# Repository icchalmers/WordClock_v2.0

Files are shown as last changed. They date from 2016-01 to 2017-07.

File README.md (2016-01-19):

# WordClock_v2.0

This is a **work-in-progress** build of a word clock. It was originally my final project as part [Fab Academy 2015](http://www.fabacademy.org/) at [Fab Lab Strathclyde](http://www.strath.ac.uk/fablab/).
You can follow the inital evolution of the clock [on my class website](http://fabacademy.org/archives/2015/eu/students/chalmers.iain/final-project-summary-wordclock20.html). The content is also mirrored to [my GitHub Pages site](http://icchalmers.github.io/final-project-summary-wordclock20.html).

This clock is an evolution of [WordClock_v1.0](https://github.com/icchalmers/WordClock_v1.0).

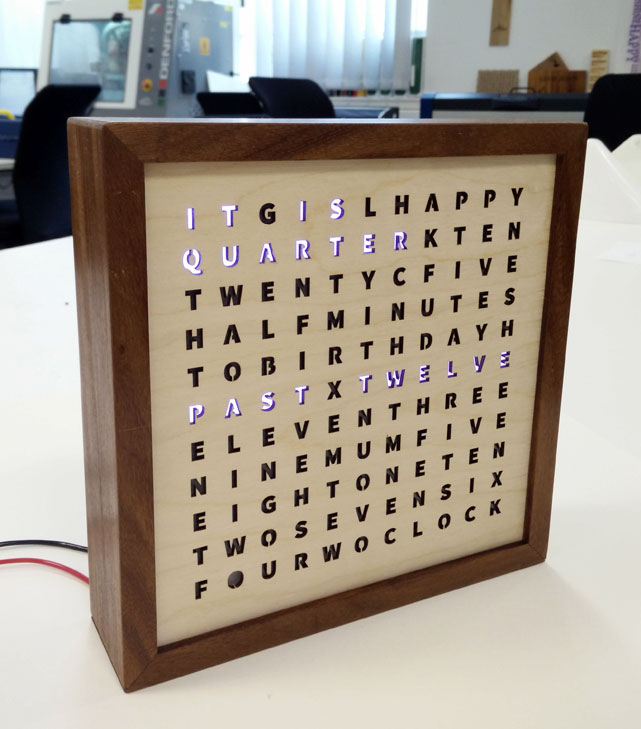
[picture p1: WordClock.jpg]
WordClock


# Project Parts

## Model
The 'Model' folder contains all the Autodesk Inventor 2015 CAD files for the clock. 

The file `Model/wordClock.ipt` is VERY customisable, but has no mounting holes for electronics or any mechanism to support the LED strips.

The 'Model/SolidifiedClockToMake' folder contains a locked down version of the clock i.e. it uses a grid of 11x11. Some parameters may or may not still be adjustable. It has additional holes added to the middle plate for mounting control electronics and holding the LED strips in place.

The main file for the clock is `wordClock_NonParametric.ipt`. The other .ipt files are the individual pieces and are derived from `wordClock_NonParametric.ipt`. They have been compensated for laser kerf using the "kerf" parameter in the master model.

The file `PartsForExport.dwg` has a layout of each of the individual parts. If you change a parameter in the master model, update the individual parts and then update the .dwg.

The lettering is added in CorelDraw - Inventor is a bit rubbish at handling text. I used a modified version of [Source Sans Pro](https://www.google.com/fonts/specimen/Source+Sans+Pro) i.e. I added little structures to support the internal parts of letters.

## hw
The 'hw' folder has the KiCAD files for the two PCB designs: the main control board and the power distribution boards. The power distribution boards also help hold the LED strips in place.

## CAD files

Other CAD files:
Model/SolidifiedClockToMake/PartsForImport_Ply3mm_Kerf0.05mm.dwg
Model/SolidifiedClockToMake/PartsLayout.dwg
Model/SolidifiedClockToMake/Back.ipt
Model/SolidifiedClockToMake/Bottom.ipt
Model/SolidifiedClockToMake/Front.ipt
Model/SolidifiedClockToMake/FrontGrid.ipt
Model/SolidifiedClockToMake/GridHo.ipt
Model/SolidifiedClockToMake/GridVert.ipt
Model/SolidifiedClockToMake/LEDSupport.ipt
Model/SolidifiedClockToMake/Left.ipt
Model/SolidifiedClockToMake/Middle.ipt
Model/SolidifiedClockToMake/Right.ipt
Model/SolidifiedClockToMake/Top.ipt
Model/SolidifiedClockToMake/wordClock_NonParametric.ipt
Model/wordClock.ipt

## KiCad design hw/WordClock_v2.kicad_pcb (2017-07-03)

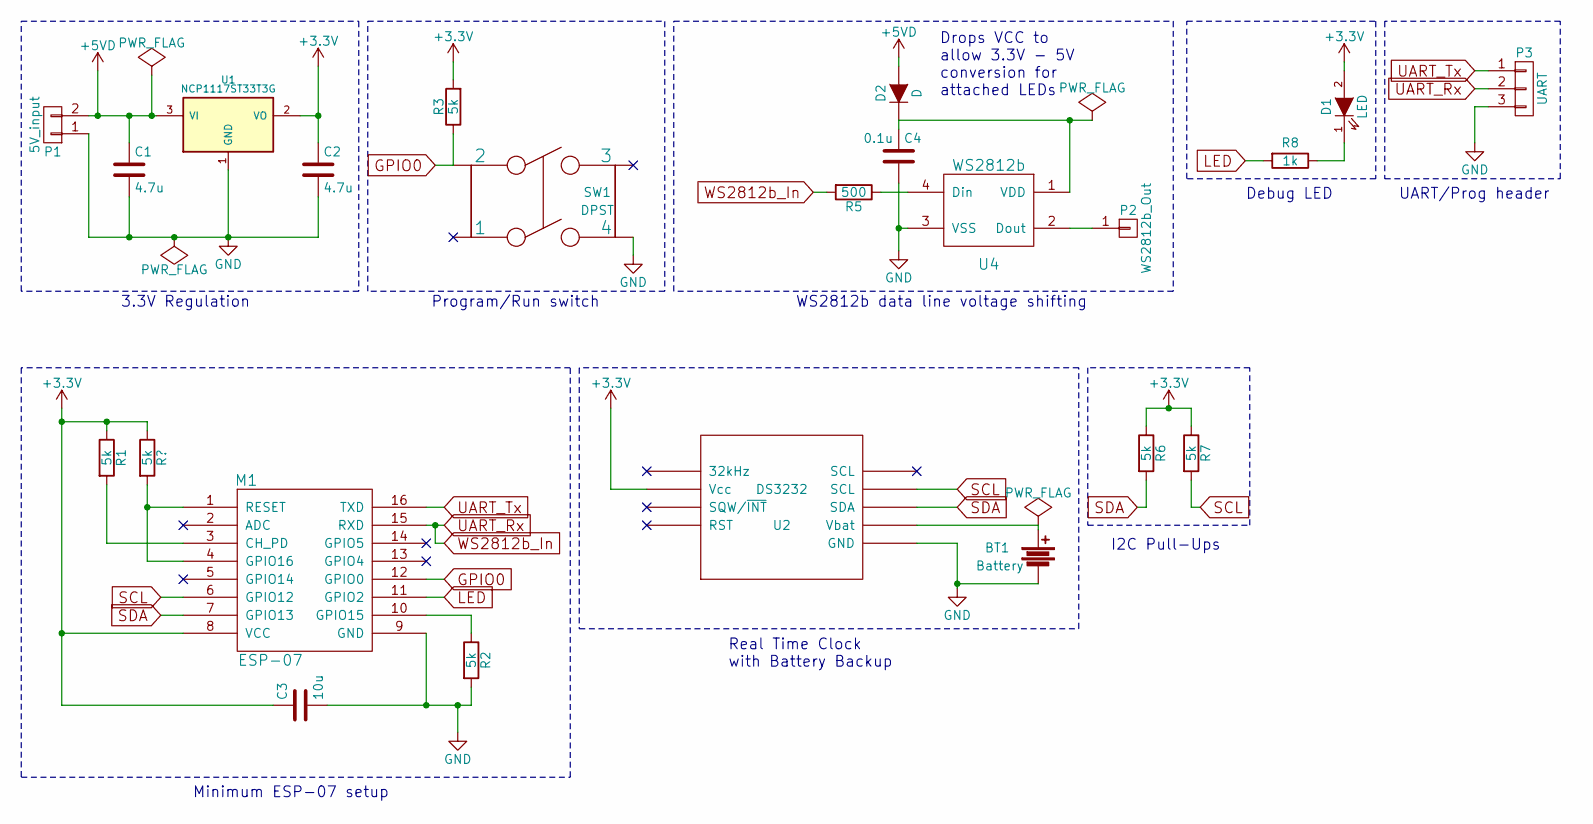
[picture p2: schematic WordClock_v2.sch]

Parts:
BT1: Battery; Battery_Holder_Cell_20mm_smd
C1, C2: 4.7u; C_1206_HandSoldering_IainEdit
C3: 10u; C_1206_HandSoldering_IainEdit
C4: 0.1u; C_1206_HandSoldering_IainEdit
D1: LED; C_1206_HandSoldering_IainEdit
D2: D; SOD-123F_HandSolder
M1: ESP-07
P1: 5V_input; Socket_Strip_Straight_1x02
P2: WS2812b_Out; Socket_Strip_Straight_1x01
P3: UART; Socket_Strip_Straight_1x03_IainEdit
R1, R2, R3, R6, R7: 5k; C_1206_HandSoldering_IainEdit
R5: 500; C_1206_HandSoldering_IainEdit
R8: 1k; C_1206_HandSoldering_IainEdit
SW1: DPST; FSM2JSMA_DPST_PushButton
U1: NCP1117ST33T3G; SOT223_HandSolder
U2: DS3232; Maxim_SOIC-20_W20-H2
U4: WS2812b; WS2812b_handsolder

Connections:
+3V3: C2.1, C3.1, D1.2 (A), M1.8 (VCC), R1.1, R3.2, R6.1, R7.1, U1.2 (VO), U2.4 (Vcc); also elsewhere on the board
+5VD: C1.1, D2.2 (A), P1.2, U1.3 (VI)
GND: BT1.2, C1.2, C2.2, C3.2, C4.2, M1.9 (GND), P1.1, P3.3, R2.2, SW1.4, U1.1 (GND), U2.15 (GND), U4.3 (VSS)
GPIO0: M1.12 (GPIO0), R3.1, SW1.2
LED: M1.11 (GPIO2), R8.2
unnamed: BT1.1, U2.16 (Vbat)
unnamed: C4.1, D2.1 (K), U4.1 (VDD)
unnamed: D1.1 (K), R8.1
unnamed 8: M1.1 (RESET), M1.4 (GPIO16); also elsewhere on the board
unnamed: M1.3 (CH_PD), R1.2
unnamed: M1.10 (GPIO15), R2.1
unnamed: P2.1, U4.2 (Dout)
unnamed: R5.1, U4.4 (Din)
SCL: M1.6 (GPIO12), R7.2, U2.18 (SCL)
SDA: M1.7 (GPIO13), R6.2, U2.17 (SDA)
UART_Rx: M1.15 (RXD), P3.2, R5.2
UART_Tx: M1.16 (TXD), P3.1

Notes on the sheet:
3.3V Regulation
WS2812b data line voltage shifting
Real Time Clock with Battery Backup
I2C Pull-Ups
Debug LED
UART/Prog header
Program/Run switch
Minimum ESP-07 setup
Drops VCC to allow 3.3V - 5V conversion for attached LEDs

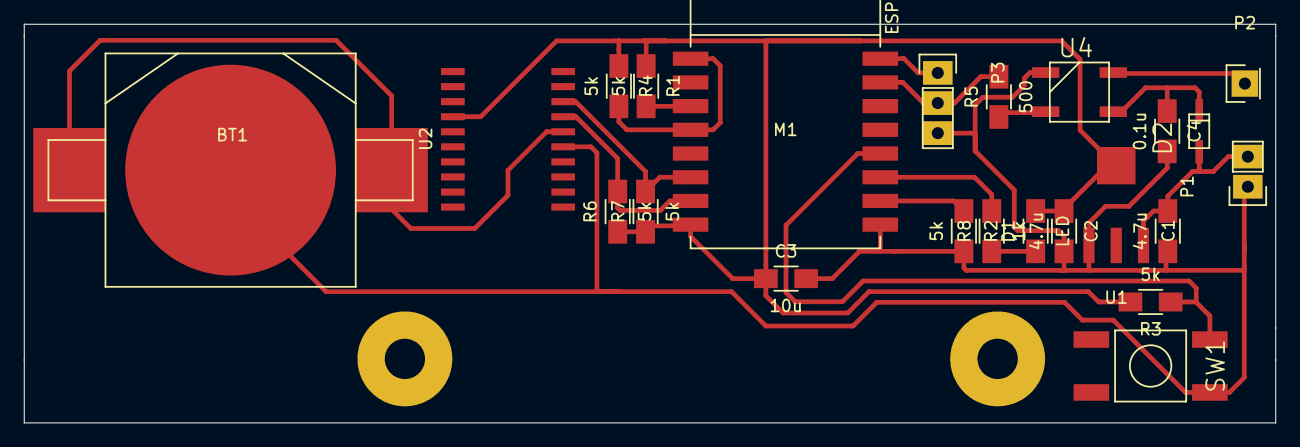
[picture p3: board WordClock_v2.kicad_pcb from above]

Board: 2 copper layers, 105.5 x 33.6 mm, 23 parts (0 on the bottom side), 17 nets.

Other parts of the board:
R4: 5k; C_1206_HandSoldering_IainEdit

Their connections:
+3V3: R4.1; also elsewhere on the board
unnamed 8: R4.2; also elsewhere on the board

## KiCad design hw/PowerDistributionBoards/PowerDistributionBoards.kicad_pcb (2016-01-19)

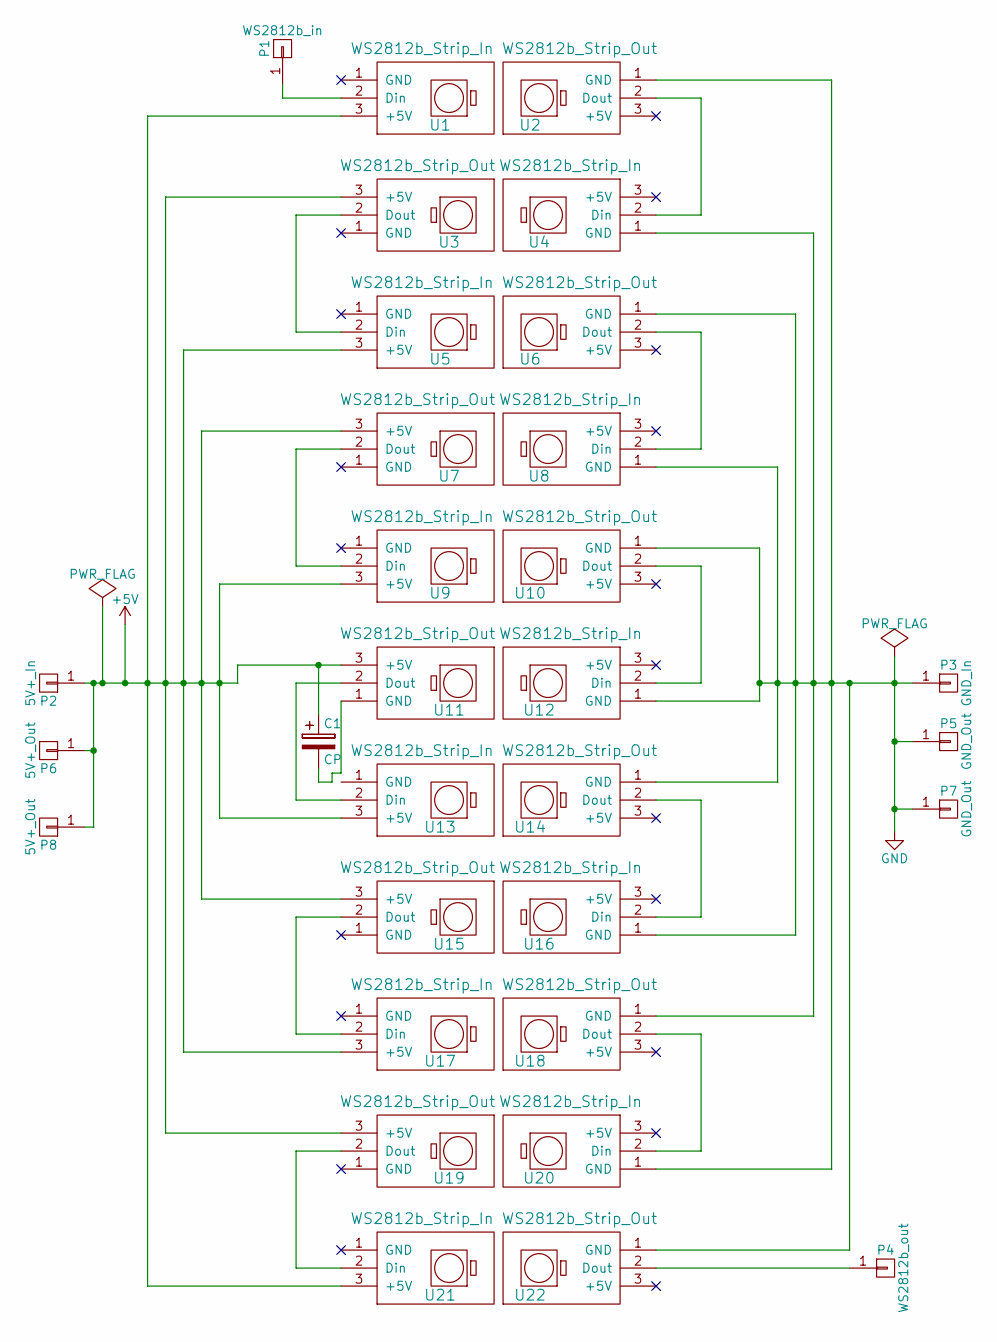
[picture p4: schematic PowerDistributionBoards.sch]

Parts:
C1: CP; Elko_vert_11.5x8mm_RM3.5
P1: WS2812b_in; Socket_Strip_Straight_1x01
P2: 5V+_In; Socket_Strip_Straight_1x01
P3: GND_In; Socket_Strip_Straight_1x01
P4: WS2812b_out; Socket_Strip_Straight_1x01
P5, P7: GND_Out; Socket_Strip_Straight_1x01
P6, P8: 5V+_Out; Socket_Strip_Straight_1x01
U1, U4, U5, U8, U9, U12, U13, U16, U17, U20, U21: WS2812b_Strip_In; WS2812b_strip_conn
U2, U3, U6, U7, U10, U11, U14, U15, U18, U19, U22: WS2812b_Strip_Out; WS2812b_strip_conn

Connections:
+5V: C1.1, P2.1, P6.1, P8.1, U1.3 (+5V), U3.3 (+5V), U5.3 (+5V), U7.3 (+5V), U9.3 (+5V), U11.3 (+5V), U13.3 (+5V), U15.3 (+5V), U17.3 (+5V), U19.3 (+5V), U21.3 (+5V)
GND: P3.1, P5.1, P7.1, U2.1 (GND), U4.1 (GND), U6.1 (GND), U8.1 (GND), U10.1 (GND), U12.1 (GND), U14.1 (GND), U16.1 (GND), U18.1 (GND), U20.1 (GND), U22.1 (GND)
unnamed: C1.2, U11.1 (GND)
unnamed: P1.1, U1.2 (Din)
unnamed: P4.1, U22.2 (Dout)
unnamed: U2.2 (Dout), U4.2 (Din)
unnamed: U3.2 (Dout), U5.2 (Din)
unnamed: U6.2 (Dout), U8.2 (Din)
unnamed: U7.2 (Dout), U9.2 (Din)
unnamed: U10.2 (Dout), U12.2 (Din)
unnamed: U11.2 (Dout), U13.2 (Din)
unnamed: U14.2 (Dout), U16.2 (Din)
unnamed: U15.2 (Dout), U17.2 (Din)
unnamed: U18.2 (Dout), U20.2 (Din)
unnamed: U19.2 (Dout), U21.2 (Din)

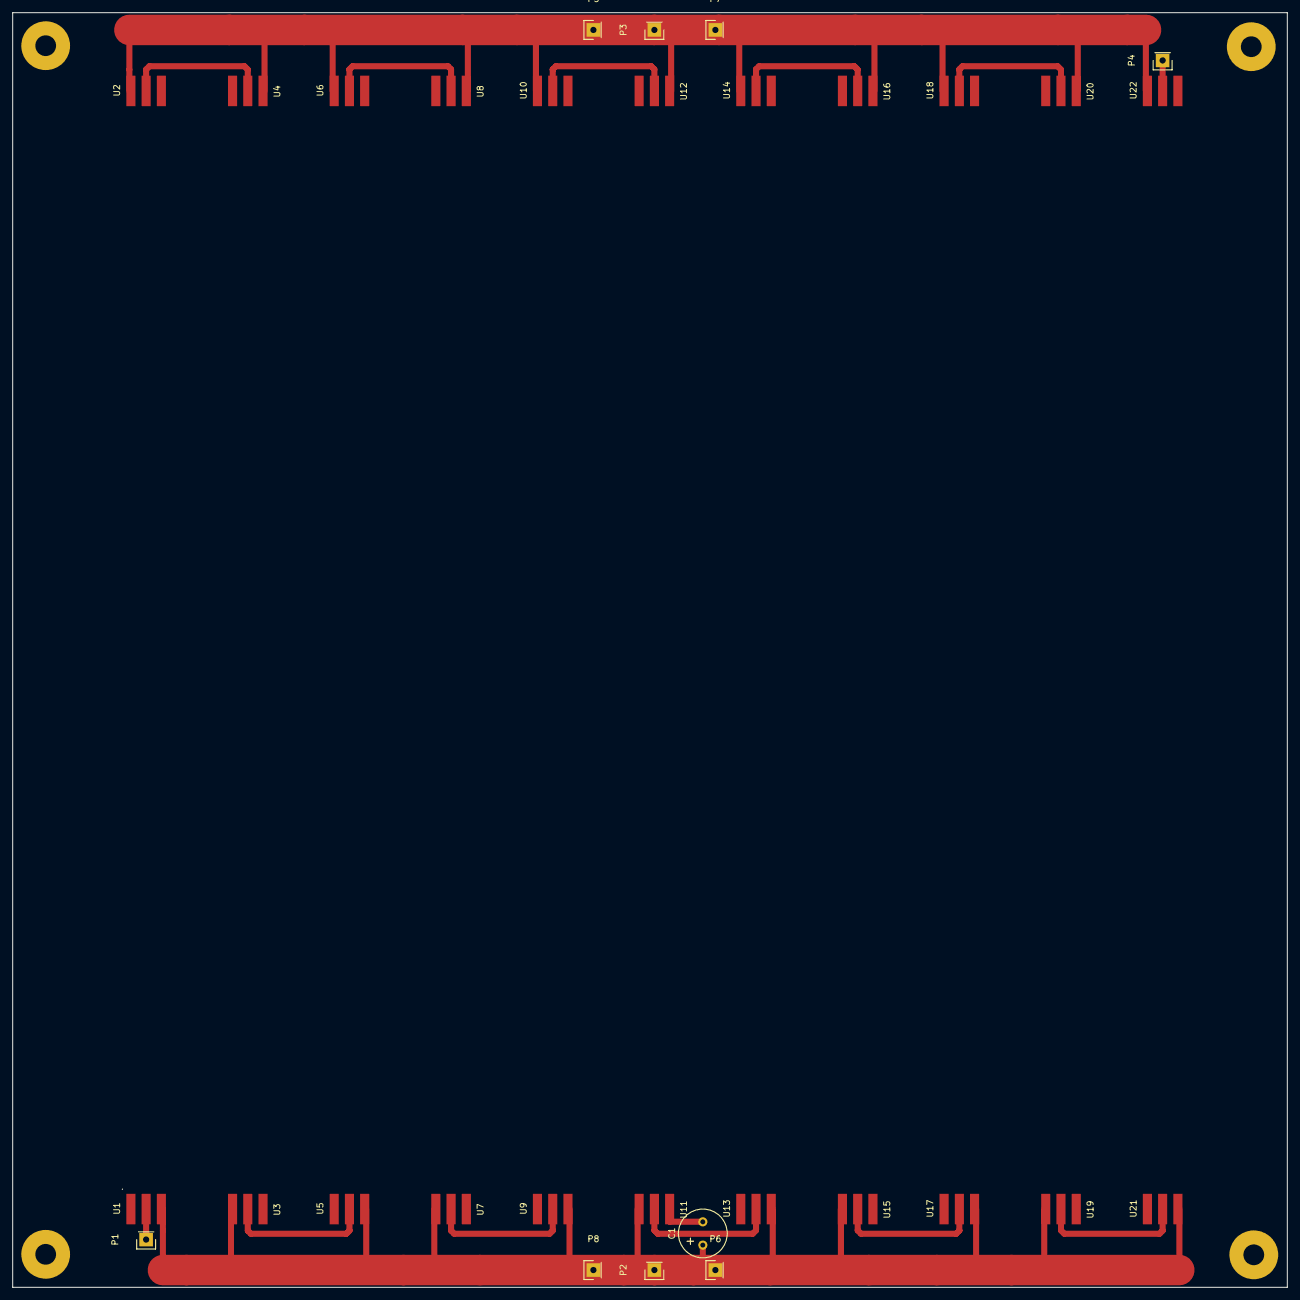
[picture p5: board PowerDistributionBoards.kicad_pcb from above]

Board: 2 copper layers, 209.0 x 209.0 mm, 31 parts (0 on the bottom side), 15 nets.

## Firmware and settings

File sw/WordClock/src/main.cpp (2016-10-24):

/*******************************************************************************
* FILENAME : main.cpp
*
* DESCRIPTION :
*     An ESP8266 and WS2812b LED based chaos word clock
*
*     Make sure to fill in the details in "userConfig_example.h" and re-save it
*     as "userConfig.h".
*
* LINKS :
*     https://github.com/icchalmers/WordClock_v2.0
*
*
* http://fabacademy.org/archives/2015/eu/students/chalmers.iain/final-project-summary-wordclock20.html
*
* AUTHOR : Iain Chalmers
*
* Copyright (c) 2016 Iain Chalmers
*
* START DATE : 5th July 2016
*
*******************************************************************************/

#include "Arduino.h"
#include <stdint.h>
#include <array>
#include <vector>
#include "userConfig.h"
#include <ESP8266WiFi.h>
#include <ESP8266mDNS.h>
#include <DNSServer.h>
#include <ESP8266WebServer.h>
#include <WiFiManager.h>
#include "./OTA.hpp"
#include "./WS2812bDisplay.hpp"
#include "./wordList.hpp"

extern const char *ssid;
extern const char *password;
extern const char *MDNSName;
extern const uint16_t pixel_count;

WS2812bDisplay display(pixel_count);

void setup() {
  Serial.begin(115200);

  // Debug LED
  DEBUG_LED_OFF
    pinMode(DEBUG_LED, OUTPUT);

  display.init();

  Serial.println("Booting");
  display.setStatus(DISPLAY_STATUS_INIT);

  // Start the wifi manager. If the clock can't connect to a wifi network it
  // connected to previosuly, it puts up it's own AP called "WordClock". When
  // the user connects to it, the captive portal takes them to a config page
  // so that they can configure the wifi. The portal stays open for 10
  // minutes.
  WiFiManager wifiManager;
  wifiManager.setTimeout(600); // 600s = 10 minutes

  if (!wifiManager.autoConnect("WordClock")) {
    Serial.println("Failed to connect and timeout reached");
    display.setStatus(DISPLAY_STATUS_WIFI_DISCONNECTED);
  } else {
    display.setStatus(DISPLAY_STATUS_OK);
    Serial.println("Ready");
  }

  ota_init(MDNSName);
}

void loop() {
  ArduinoOTA.handle(); // must be called frequently

  display.setPixelColor(word_it, display.red);
  display.setPixelColor(word_is, display.green);
  display.show();
}

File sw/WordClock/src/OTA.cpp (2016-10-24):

#include "Arduino.h"
#include "OTA.hpp"
#include <ArduinoOTA.h>
#include "./WS2812bDisplay.hpp"

extern WS2812bDisplay display;

void ota_init(const char *hostname) {
  ArduinoOTA.setHostname(hostname);

  // Set the callbacks to handle OTA events
  ArduinoOTA.onStart(&_ota_onStart);
  ArduinoOTA.onProgress(&_ota_onProgress);
  ArduinoOTA.onEnd(&_ota_onEnd);
  ArduinoOTA.onError(&_ota_onError);

  // Start the OTA handler
  ArduinoOTA.begin();
}

void _ota_onStart() {
  Serial.println("Starting an OTA update...");
  _ota_displayStart();
}

void _ota_onEnd() {
  Serial.println("\r\nOTA update finished. Restarting.");
  _ota_displayEnd();
}

void _ota_onError(ota_error_t error) {
  Serial.printf("Error[%u]: ", error);

  switch (error) {
  case OTA_AUTH_ERROR:
    Serial.println("Auth Failed");
    break;

  case OTA_BEGIN_ERROR:
    Serial.println("Begin Failed");
    break;

  case OTA_CONNECT_ERROR:
    Serial.println("Connect Failed");
    break;

  case OTA_RECEIVE_ERROR:
    Serial.println("Receive Failed");
    break;

  case OTA_END_ERROR:
    Serial.println("End Failed");
    break;

  default:
    Serial.println("Unknown error");
  }
  _ota_displayError(error);
  Serial.println("\r\nRestarting ESP8266");
  ESP.restart();
}

void _ota_onProgress(int progress, int total) {
  int percentage_complete = (progress / (total / 100));

  Serial.printf("Progress: %u%%\r", percentage_complete);

  _ota_displayProgress(percentage_complete);
}

// Makes the top line of the display yellow on OTA start
void _ota_displayStart() {
  display.clear();

  for (uint16_t i = 1; i < PIXELS_PER_LINE + 1; i++) {
    display.setPixelColor(i, display.yellow);
  }
  display.show();
  display.setStatus(DISPLAY_STATUS_OTA);
}

// Makes the top line fill up green to show progress
void _ota_displayProgress(int percentage_complete) {
  int progress_end_pixel = percentage_complete / PIXELS_PER_LINE;

  for (uint16_t i = 1; i < progress_end_pixel; i++) {
    display.setPixelColor(i, display.green);
  }
  display.show();
}

// Makes the top line all green when OTA update is finished, then clears the
// screen before reset.
void _ota_displayEnd() {
  for (uint16_t i = 1; i < PIXELS_PER_LINE + 1; i++) {
    display.setPixelColor(i, display.green);
  }
  display.show();
  delay(1000); // Should really avoid delay() and use Ticker instead...
  display.clear();
  display.setStatus(DISPLAY_STATUS_DISABLE);
}

// Makes the top line of the display red on an OTA update error
void _ota_displayError(ota_error_t error) {
  for (uint16_t i = 1; i < PIXELS_PER_LINE + 1; i++) {
    display.setPixelColor(i, display.red);
  }
  display.show();
}

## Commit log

2016-01-19 Initial commit
    updated readme
    Added top plate
    Added side plate and set dimensions to match v1.0
    Fixed contraint on top plate stopping being able to increase tabs on front side
    Added mirrors of existing side top and face to make complete box
    Added the middle plate
    Added the construction for the grid
    Added the LED slots
    Added vertical grid divider plus slots
    Added chamfer on vert grid tabs
    Added horizontal slat and slots to join with verticle grid pieces
    Added small chamfer to grid horizontal piece slots. Should help putting together and have minimal light leakage
    Added vent holes and power socket hole to back plate
    Finished wordClock.ipt. Derived wordClock_NonParametric.ipt to ad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
    [Back.ipt, Bottom.ipt, Front.ipt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]
2016-01-19 deleting old out-of-date images and cut files, and updating the README
2016-07-08 Getting rid of old Arduino IDE based code. It wasn't even compiling properly in a more recent IDE. The multi-INO file system is pretty terrible. Also library management is basically non-existent. Goi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
2016-08-18 Adding basic macros for using the debug LED
2016-08-18 Updated PCB to use RDX0/GPIO3 for WS2812b in order to use the NeoEps8266Dma800KbpsMethod of Makuna's NeoPixelBus library
    [WordClock_v2.kicad_pcb, WordClock_v2.sch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]
2016-08-18 Added the start of a display driver for controlling all the LEDs on the board
2016-08-18 adding includes to main for wifimanager, as suggested in it's example code. It compiles fine in platformio without, but might be necessary if used in the Arduino IDE
2016-08-22 Adding underscore to functions that should not be called externally. Really this should be converted to an OTAManager class. Also adding protoypes for functions to display current OTA status on the d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
2016-08-22 Forgot to update display on OTA error
    [OTA.cpp]
2016-08-25 Making colour definitions in the display class be static so can use without creating instance of the class if necessary. Also changed to lower case as upper case was a fallover from when I initially 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
2017-07-01 Switched to diode-drop method of voltage conversion and changed from switch to push button for entering programming mode
    [WordClock_v2.kicad_pcb, WordClock_v2.sch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]
2017-07-01 fixed clearnace issue for making on the denford
    [WordClock_v2.kicad_pcb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]
2017-07-01 adding files for use on the Denford PCB engraver
    [PowerDistributionBoards_SingleSide_withCap_Denford.drl, WordClock_v2_denford.drl]
2017-07-01 adding power flag annotation
    [WordClock_v2.sch]
2017-07-03 Updated CH_PD and RST on ESP to use their own pullup resistors. Attached GPIO16 to RST to allow wake from deep sleep
    [WordClock_v2.kicad_pcb, WordClock_v2.sch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]
